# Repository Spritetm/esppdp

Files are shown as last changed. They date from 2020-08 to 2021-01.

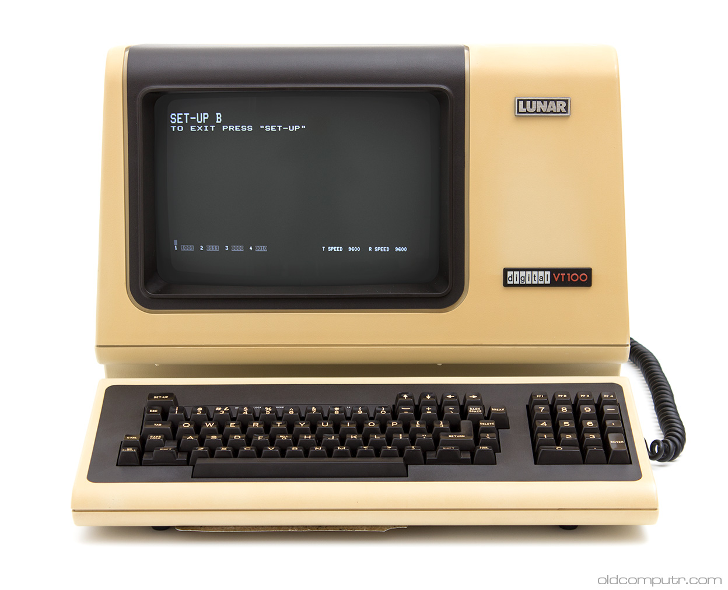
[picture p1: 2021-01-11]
case/source-images/digital_vt100-7349.jpg

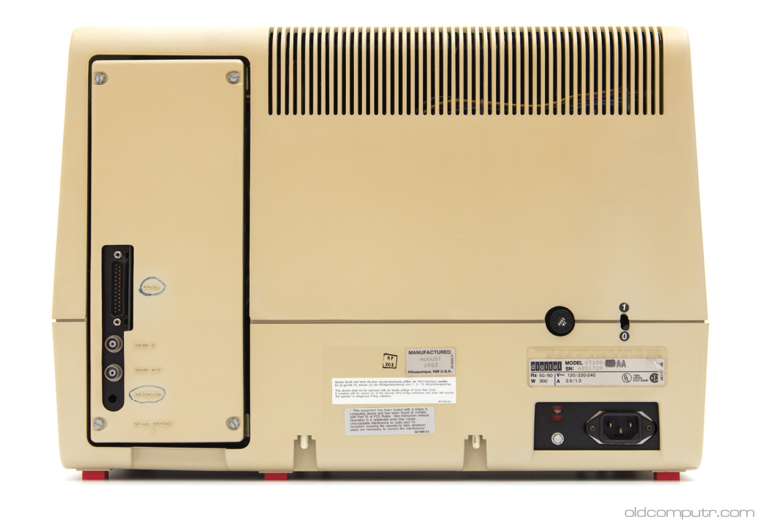
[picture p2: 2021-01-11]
case/source-images/digital_vt100-back-7363.jpg

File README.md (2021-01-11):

#What is this?

This is the source repository for esppdp, which is a tiny VT-102 scale model housing an
ESP32 emulating a PDP11. You can connect a BlueTooth keyboard to it and play the
original Tetris, or do some die-hard computing on 2.11BSD.

#Why?

Well, someone had to put back the 'mini' in 'minicomputer', right?

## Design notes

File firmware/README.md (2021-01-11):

This is the code for a PDP11 simulation on an ESP32. It also contains some code for turning
an attached LCD into a VT52/IE15 terminal as well as using a BlueTooth keyboard as an input device.

Flash it onto a board, turn it on. If you want to use a keyboard, make sure it's discoverable
over BlueTooth within the first few seconds of the ESP32 turning on. Note that the paired
BT device afterwards will be detected automatically. Unfortunately there's no easy way to clear
the pairing to use a different keyboard without erasing the flash of the ESP32 (idf.py erase-flash).

This firmware works on either the final hardware (as detailed in the ../pcb directory) as well
as a standard ESP32-Wrover-Kit development board + LCD. You can configure which board to run on
in menuconfig. (If your LCDs backlight doesn't turn on, you selected the wrong one.)

The firmware embeds a floppy disk containing RTX-11 as well as Tetris, and will start this up
automatically unless a FAT-formatted micro-SD-card with a file called 'rq.dsk' is detected. If
this file is detected, the firmware will configure a larger PDP11 and will start from the disk.
A pre-configured 2.11BSD disk has been provided in ../hard-disk-image.

To quicken uploads (if you're developing the code), you can comment out the
spiffs_create_partition_image line in CMakeLists.txt. This'll stop 'idf.py flash'
from uploading the Tetris floppy every time.

This firmware is developed on the current (11 jan 2021) master branch of ESP-IDF, but will likely
compile on ESP-IDF 4.2 and possibly other versions.

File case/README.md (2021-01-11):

This is the OpenSCAD source for the VT102 model.

Note that this requires Threadlib (for the two M3 fasteners), which is located at
https://github.com/adrianschlatter/threadlib

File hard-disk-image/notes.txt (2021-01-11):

This disk is a full-on 2.11bsd installation. Additionaly, the install is modified to add
wifid to the package. After booting this, you should be able to login as root with
the password 'esppdp11', or as the unprivileged user 'pdp11' with the same password.

To connect to a wifi network, as root, use wifid. For instance, to connect to the
access point called MyWLAN with the password MyPassword, use:
wifid -connect MyWLAN MyPassword
wifid will remember the last-connected ssid and password and reconnect to that
network on device startup.

One last note: Be sure to always shut down your 2.11BSD session. The file system is somewhat
prone to corruption if you just do the equivalent of pulling the plug instead of using
the 'halt' command to shut things down.

To use the disk, unzip and put the resulting file in the root of a FAT32-formatted 
micro-SD-card. The ESP32 SimH build will automatically pick it up and boot it. Do note
that starting up requires some manual interaction: you have to press 'enter' at the very 
first prompt ':' to boot into the OS. Then, at the prompt that follows about a minute later
'#', press ctrl-D to exit single-user mode and boot into the full system.

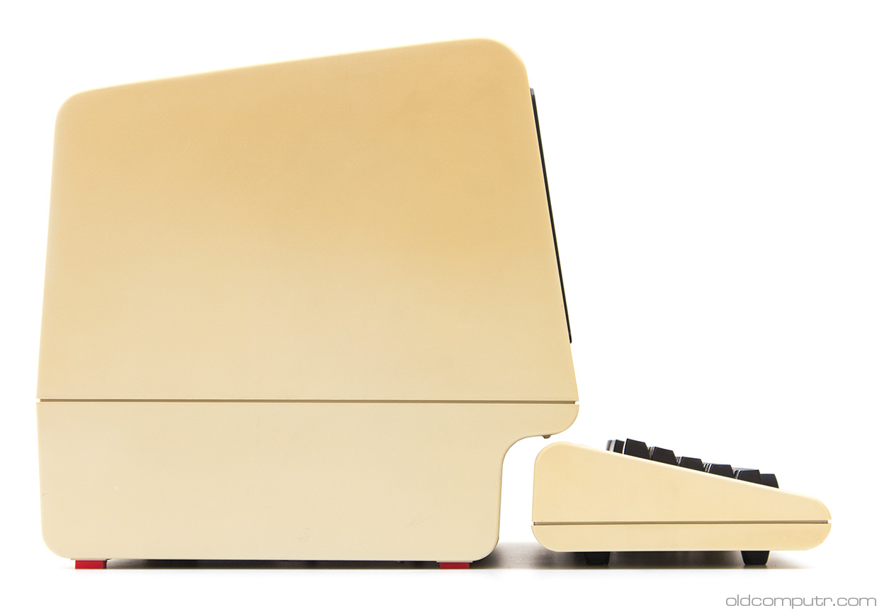
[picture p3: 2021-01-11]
case/source-images/digital_vt100-side-7362.jpg

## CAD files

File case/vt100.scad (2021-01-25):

//VT102 scale model, top+bottom half + fastener locations to hold them together, plus
//PCB and LCD mounts.
/*
 * ----------------------------------------------------------------------------
 * "THE BEER-WARE LICENSE" (Revision 42):
 * Jeroen Domburg <jeroen@spritesmods.com> wrote this file. As long as you retain 
 * this notice you can do whatever you want with this stuff. If we meet some day, 
 * and you think this stuff is worth it, you can buy me a beer in return. 
 * ----------------------------------------------------------------------------
 */

use <threadlib/threadlib.scad>

pix_scale=13; //this many pixels in one mm
$fs=0.3;

//in pixels
screen_slot_size=10;
vent_slot_size=6;
vent_slot_off=12;
slot_depth=15;
hull_thickness_mm=2.5;
hull_thickness=hull_thickness_mm*pix_scale;
lip_height=3;
show_lcd=0;

faceplate_angle=9;

/* Set this to 1 for some things that take long to render (specifically the ventilation gratings and
the DEC logo badge) */
fast_render=0;

/* What to render. Use values from 1 to 7 to select a view. For 3d printing, you want to
render 3 (bottom half) and 4 (top half). */
render_tp=3;

if (render_tp==1 || render_tp==2) {
    pcb();
    intersection() {
        union() {
            vt100_model_top();
        }
        if (render_tp==1) {
            translate([-500, 0, -500]) cube([1000,1000,1000]);
        } else {
            translate([25, -500, -500]) cube([1000,1000,1000]);
        }
    }
} else if (render_tp==3 || render_tp==4 || render_tp==5) {
    intersection() {
        union() {
            if (render_tp==3 || render_tp==5) {
                vt100_model_bottom();
            }
            if (render_tp==4 || render_tp==5) {
                rotate([0,180,0])  vt100_model_top();
            }
        }
        //translate([-500, 0, -500]) cube([1000,1000,1000]);
    }
} else if (render_tp==6) {
    pcb();
} else if (render_tp==7) {
    switch();
}


//Cutout for power switch
module switch() {
    translate([3.25, 0, 1.4]) union() {
        translate([1.5, 0, 0]) cube([2.8+3, 6.8, 1.5], center=true);
        translate([-2, 0, 0])cube([4, 3.2, 1.2], center=true);
    }
}

//PCB. Make ext 1 to also include room where plug/card goes in.
module pcb(ext) {
    exsz=ext?10:0;
    color([0.2,0.9,0]) translate([9,28,-13.5]) {
        union() {
            rotate([90,0,0]) linear_extrude(height=1.7) polygon(points=[
                [-2,13.5],[-1.3,0],[41,0],[41,49],[0,43]
            ]);
            translate([14.3,0,13.8]) cube([31.6,1,18]);
            translate([-1.5,-2.8-1.6,2.7]) rotate([0, -3, 0])translate([-exsz,0,0]) cube([exsz+6.5, 2.8, 8]);
            translate([-1.7,-2.5-1.6,19.3]) rotate([0, 4, 0])translate([-exsz,0,0]) cube([exsz+17.7, 2.5, 14]);
        }
    }
}


module lcd_placeholder_thingies() {
    scale(1/pix_scale) union() {
        translate([590 ,0, 455]) rotate([0,5,0]) cube([80,50,30]);
        translate([590 ,-250, 455]) rotate([0,5,0]) cube([80,50,30]);
        translate([700 ,-350, -20]) cube([70,500,50]);
    }
}

module pcb_placeholder_thingies() {
    union() {
        translate([7, 24, -13.5-1]) cube([10, 5.6, 3.5]);
        translate([8.5, 24, 27]) rotate([0,-9,0]) cube([10, 5.6, 4.5]);
        translate([47.3, 24, 31]) rotate([0,-9,0]) cube([6, 5.6, 4.5]);
    }
}


module vt100_model_top() {
    difference() {
        vt100_model();
        lip_diff();
    }
}


//inside this = bottom, outside = top
module lip_diff() {
    union() {
        translate([0, -500, -1000]) cube([1000,1000,1000]);
        difference() {
            scale(1/pix_scale) translate([55+hull_thickness/2,-922/2+hull_thickness/2,0])cube([736-hull_thickness,922-hull_thickness,lip_height*pix_scale]);
            scale(1/pix_scale) translate([200,-380,0])cube([400-hull_thickness,800-hull_thickness,lip_height*pix_scale]);
        }
    }
}

module vt100_model_bottom() {
    lhs=lip_height*pix_scale;
    intersection() {
        vt100_model();
        lip_diff();
    }
}

module screwpost() {
    translate([25,0,-16]) {
        cylinder(49.5, d=5.5+4);
    }
}

module screwpost_inside() {
    translate([25,0,-50-1.5]) {
        cylinder(50, d=5.5);
        cylinder(50+1.51, d=3);
        translate([0,0,51.5]) cylinder(0.2, d=5); //compensate for build plate building artifact top
        translate([0,0,35]) cylinder(0.5, d=8); //compensate for build plate building artifact bot
        translate([0,0,50+9]) rotate([180,0,0]) tap("M3", turns=15);
    }
}

module vt100_model() {
    render(8) difference() {
        union() {
            scale(1/pix_scale) vt100_hull();
            lcd_placeholder_thingies();
            pcb_placeholder_thingies();
            translate([0,18,0]) screwpost();
            translate([0,-18,0]) screwpost();
            translate([4+hull_thickness_mm,-33,hull_thickness_mm-16]) cube([6.5,12, 2]);
        }
        translate([0,18,0]) screwpost_inside();
        translate([0,-18,0]) screwpost_inside();
        translate([1.5+hull_thickness_mm, -33+6, hull_thickness_mm-15.2]) switch();
        lcd();
        pcb(1);
        translate([0, 19, -12]) cube([5.5, 12, 12]);
    }

}

module lcd() {
   if (show_lcd == 1) {
    //sizes are from KD018QVFMN010 specsheet
    tol=0.25; //tolerance on outside dimensions
    translate([721/pix_scale, -400/pix_scale,23/pix_scale]) rotate([-90-faceplate_angle,180, -90]) union() {
        translate([-tol/2,-tol/2,-tol/2]) cube([46.7+tol, 34.7+tol, 2.50+tol]); //display itself
        %translate([3.2, 4.03, 0]) cube([35.52, 26.64, 2.50+tol+0.1]); //visible area, stick out a bit
    }
   }
}



module rounded_cube(c, s) {
    hull() {
        translate([s,s,s]) sphere(r=s);
        translate([c[0]-s,s,s]) sphere(r=s);
        translate([s,c[1]-s,s]) sphere(r=s);
        translate([c[0]-s,c[1]-s,s]) sphere(r=s);
        translate([s,s,c[2]-s]) sphere(r=s);
        translate([c[0]-s,s,c[2]-s]) sphere(r=s);
        translate([s,c[1]-s,c[2]-s]) sphere(r=s);
        translate([c[0]-s,c[1]-s,c[2]-s]) sphere(r=s);
    }
}

//black rounded cosmetical cube thing on the case the screen is located in
module vt100_screencube(m) {
    translate([376+m,-408+m,43+m])rounded_cube([500-m*2,593-m*2,500-m*2],40-m);
}


module vt100_hull() {
    difference() {
        vt100_case_w_screen();
        vt100_case_solid(hull_thickness);
    }
}


module vt100_case_w_screen() {
    difference() {
        vt100_case_outer();
        union() {
            translate([784-40,0,-15]) rotate([0,-faceplate_angle,0])rotate([90,0,90]) hull() {
                translate([-358,106,0]) cylinder(50,r1=0,r2=30);
                translate([132,106,0]) cylinder(50,r1=0,r2=30);
                translate([-358,422,0]) cylinder(50,r1=0,r2=30);
                translate([132,422,0]) cylinder(50,r1=0,r2=30);
            }
        }
    }
}


module vt100_case_outer() {
    union() {
        difference() {
            if (fast_render) {
                vt100_case_solid(0);
            } else {
                minkowski(){
                    vt100_case_solid(8);
                    sphere(d=8);
                }
            }
            union() {
                difference() {
                    vt100_screencube(0);
                    vt100_screencube(screen_slot_size);
                }
                if (!fast_render) {
                    for (i=[0:vent_slot_off:480]) { //side vents
                        translate([157+i, 215, 200]) cube([vent_slot_size, 180, 500]);
                    }
                    for (i=[0:vent_slot_off:580]) { //back vents
                        translate([242-385, -405+i, 300]) cube([300, vent_slot_size, 500]);
                    }
                }
            }
        }
        vt100_case_solid(slot_depth);
        if (!fast_render) {
            translate([740+8, 242, 100]) rotate([90-faceplate_angle,0,90]) scale(0.18) linear_extrude(height=30/0.18, convexity=10) {
                import("digital_badge.svg", convexity=10);
            }
        }
    }
}

/*

  A--------G
  /        |
 |         |
 B         |
 |    EE   |
  \      E-F
  C------D 

  X ->  Y V
*/



module vt100_case_solid(inset) {
    A=[120,150];
    B=[99,722];
    C=[56,545];
    D=[650,722];
    E=[730,628];
    EE=[657,556];
    F=[755,550];
    G=[655,112];
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

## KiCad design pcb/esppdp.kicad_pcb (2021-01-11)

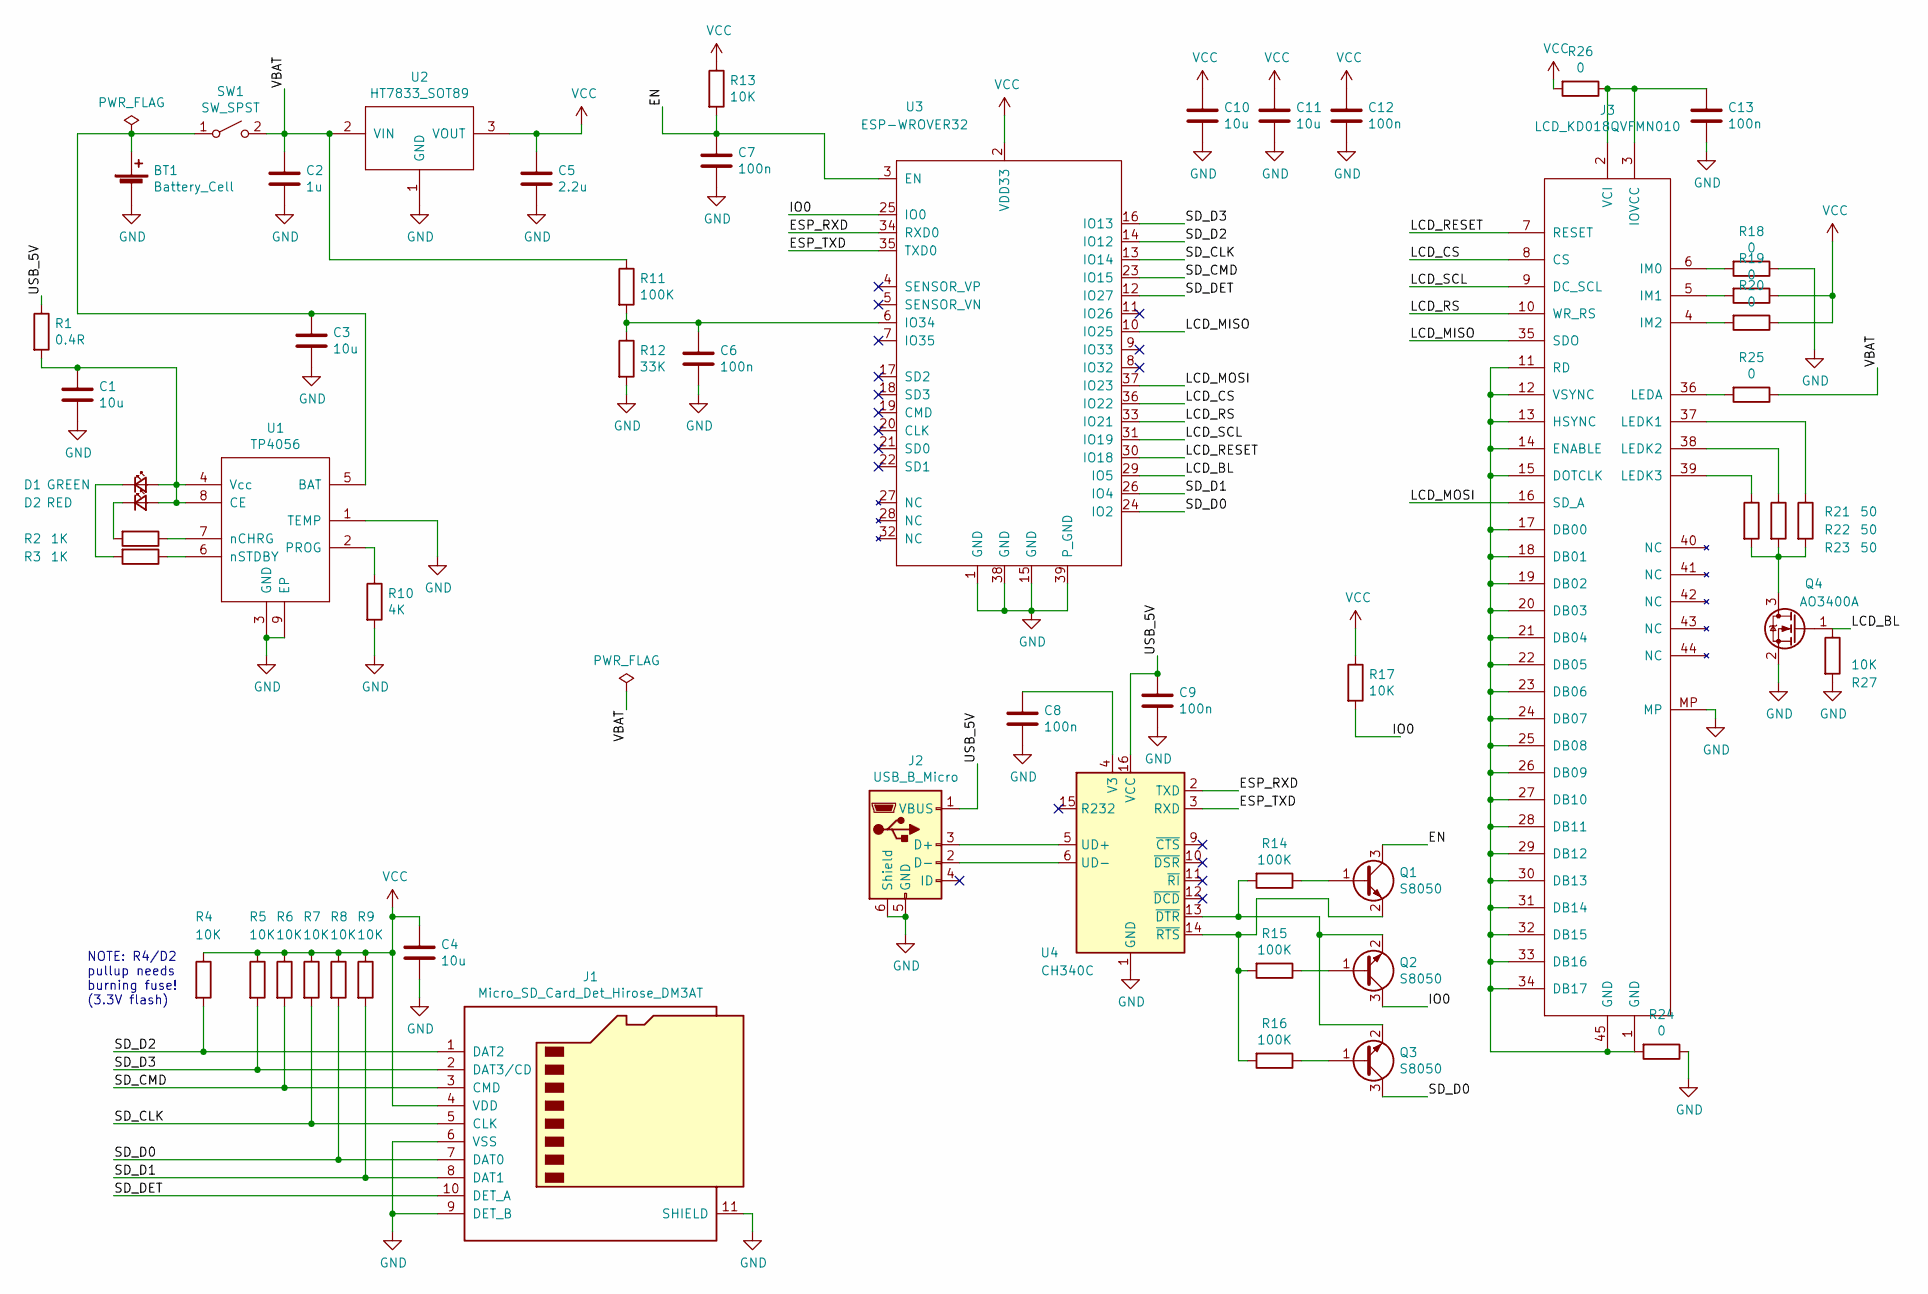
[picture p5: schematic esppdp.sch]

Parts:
BT1: Battery_Cell; PinHeader_1x02_P2.54mm_Vertical
C1, C3, C4, C10, C11: 10u; C_0805_2012Metric
C2: 1u; C_0603_1608Metric
C5: 2.2u; C_0603_1608Metric
C6, C7, C8, C9, C12, C13: 100n; C_0603_1608Metric
D1: GREEN; LED_0603_1608Metric
D2: RED; LED_0603_1608Metric
J1: Micro_SD_Card_Det_Hirose_DM3AT; microSD_HC_Hirose_DM3AT-SF-PEJM5
J2: USB_B_Micro; USB_Micro-B_China_MK5P
J3: LCD_KD018QVFMN010; Hirose_FH12-45S-0.5SH_1x45-1MP_P0.50mm_Horizontal_Descendin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
Q1, Q2, Q3: S8050; SOT-23
Q4: AO3400A; SOT-23
R1: 0.4R; R_0603_1608Metric
R2, R3: 1K; R_0603_1608Metric
R4, R5, R6, R7, R8, R9, R13, R17, R27: 10K; R_0603_1608Metric
R10: 4K; R_0603_1608Metric
R11, R14, R15, R16: 100K; R_0603_1608Metric
R12: 33K; R_0603_1608Metric
R18, R19, R20, R24, R25, R26: 0; R_0603_1608Metric
R21, R22, R23: 50; R_0603_1608Metric
SW1: SW_SPST; PinHeader_1x02_P2.54mm_Vertical
U1: TP4056; SOIC-8-1EP_3.9x4.9mm_P1.27mm_EP2.29x3mm
U2: HT7833_SOT89; SOT-89-3
U3: ESP-WROVER32; ESP-WROVER-MOD
U4: CH340C; SOIC-16_3.9x9.9mm_P1.27mm

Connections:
/EN: C7.1, Q1.3 (C), R13.2, U3.3 (EN)
/ESP_RXD: U3.34 (RXD0), U4.2 (TXD)
/ESP_TXD: U3.35 (TXD0), U4.3 (RXD)
/IO0: Q2.3 (C), R17.2, U3.25 (IO0)
/LCD_BL: Q4.1 (G), R27.1, U3.29 (IO5)
/LCD_CS: J3.8 (CS), U3.36 (IO22)
/LCD_MISO: J3.35 (SDO), U3.10 (IO25)
/LCD_MOSI: J3.16 (SD_A), U3.37 (IO23)
/LCD_RESET: J3.7 (RESET), U3.30 (IO18)
/LCD_RS: J3.10 (WR_RS), U3.33 (IO21)
/LCD_SCL: J3.9 (DC_SCL), U3.31 (IO19)
/SD_CLK: J1.5 (CLK), R7.2, U3.13 (IO14)
/SD_CMD: J1.3 (CMD), R6.2, U3.23 (IO15)
/SD_D0: J1.7 (DAT0), Q3.3 (C), R8.2, U3.24 (IO2)
/SD_D1: J1.8 (DAT1), R9.2, U3.26 (IO4)
/SD_D2: J1.1 (DAT2), R4.2, U3.14 (IO12)
/SD_D3: J1.2 (DAT3/CD), R5.2, U3.16 (IO13)
/SD_DET: J1.10 (DET_A), U3.12 (IO27)
/USB_5V: C9.1, J2.1 (VBUS), R1.1, U4.16 (VCC)
/VBAT: C2.1, R11.1, R25.1, SW1.2 (B), U2.2 (VIN)
GND: BT1.2 (-), C1.2, C2.2, C3.2, C4.2, C5.2, C6.2, C7.2, C8.2, C9.2, C10.2, C11.2, C12.2, C13.2, J1.6 (VSS), J1.9 (DET_B), J1.11 (SHIELD), J2.5 (GND), J2.6 (Shield), J3.MP, Q4.2 (S), R10.2, R12.2, R18.1, R24.1, R27.2, U1.1 (TEMP), U1.3 (GND), U1.9 (EP), U2.1 (GND), U3.1 (GND), U3.15 (GND), U3.38 (GND), U3.39 (P_GND), U4.1 (GND)
unnamed: BT1.1 (+), C3.1, SW1.1 (A), U1.5 (BAT)
unnamed: C1.1, D1.2 (A), D2.2 (A), R1.2, U1.4 (Vcc), U1.8 (CE)
unnamed: C6.1, R11.2, R12.1, U3.6 (IO34)
unnamed: C8.1, U4.4 (V3)
unnamed: C13.1, J3.2 (VCI), J3.3 (IOVCC), R26.1
unnamed: D1.1 (K), R3.2
unnamed: D2.1 (K), R2.2
unnamed: J2.2 (D-), U4.6 (UD-)
unnamed: J2.3 (D+), U4.5 (UD+)
unnamed: J3.1 (GND), J3.11 (RD), J3.12 (VSYNC), J3.13 (HSYNC), J3.14 (ENABLE), J3.15 (DOTCLK), J3.17 (DB00), J3.18 (DB01), J3.19 (DB02), J3.20 (DB03), J3.21 (DB04), J3.22 (DB05), J3.23 (DB06), J3.24 (DB07), J3.25 (DB08), J3.26 (DB09), J3.27 (DB10), J3.28 (DB11), J3.29 (DB12), J3.30 (DB13), J3.31 (DB14), J3.32 (DB15), J3.33 (DB16), J3.34 (DB17), J3.45 (GND), R24.2
unnamed: J3.4 (IM2), R20.2
unnamed: J3.5 (IM1), R19.2
unnamed: J3.6 (IM0), R18.2
unnamed: J3.36 (LEDA), R25.2
unnamed: J3.37 (LEDK1), R23.1
unnamed: J3.38 (LEDK2), R22.1
unnamed: J3.39 (LEDK3), R21.1
unnamed: Q1.1 (B), R14.1
unnamed: Q1.2 (E), R15.2, R16.2, U4.14 (~RTS)
unnamed: Q2.1 (B), R15.1
unnamed: Q2.2 (E), Q3.2 (E), R14.2, U4.13 (~DTR)
unnamed: Q3.1 (B), R16.1
unnamed: Q4.3 (D), R21.2, R22.2, R23.2
unnamed: R2.1, U1.7 (nCHRG)
unnamed: R3.1, U1.6 (nSTDBY)
unnamed: R10.1, U1.2 (PROG)
VCC: C4.1, C5.1, C10.1, C11.1, C12.1, J1.4 (VDD), R4.1, R5.1, R6.1, R7.1, R8.1, R9.1, R13.1, R17.1, R19.1, R20.1, R26.2, U2.3 (VOUT), U3.2 (VDD33)

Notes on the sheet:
NOTE: R4/D2 pullup needs burning fuse! (3.3V flash)

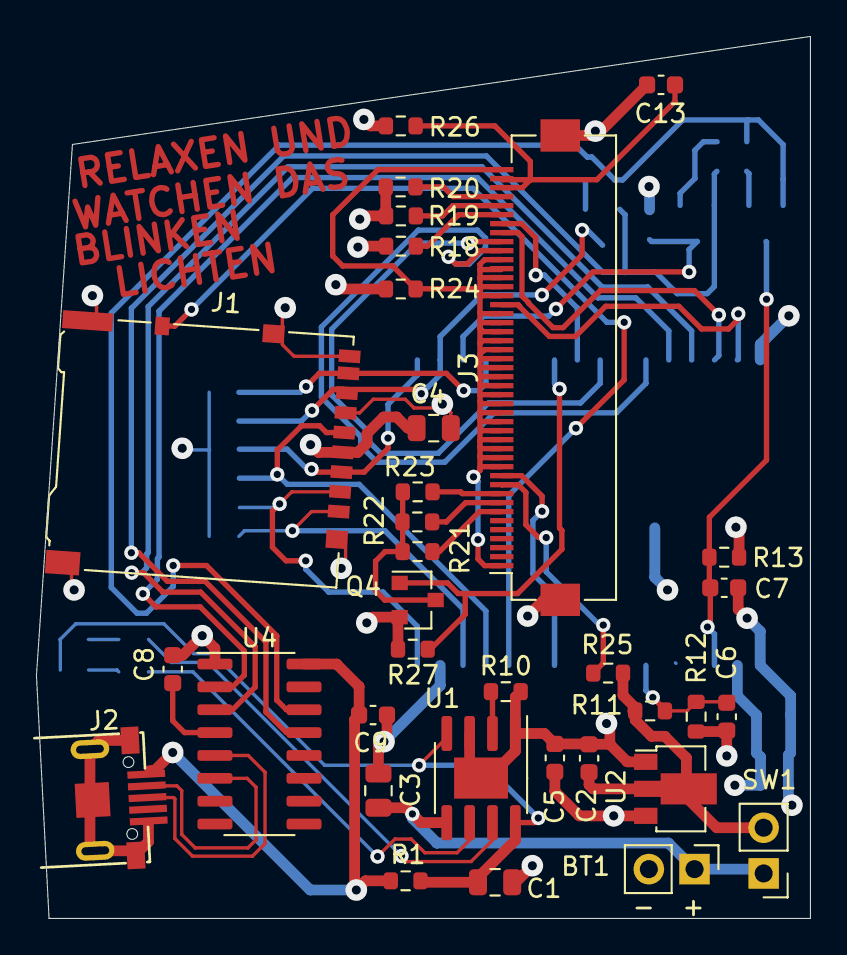
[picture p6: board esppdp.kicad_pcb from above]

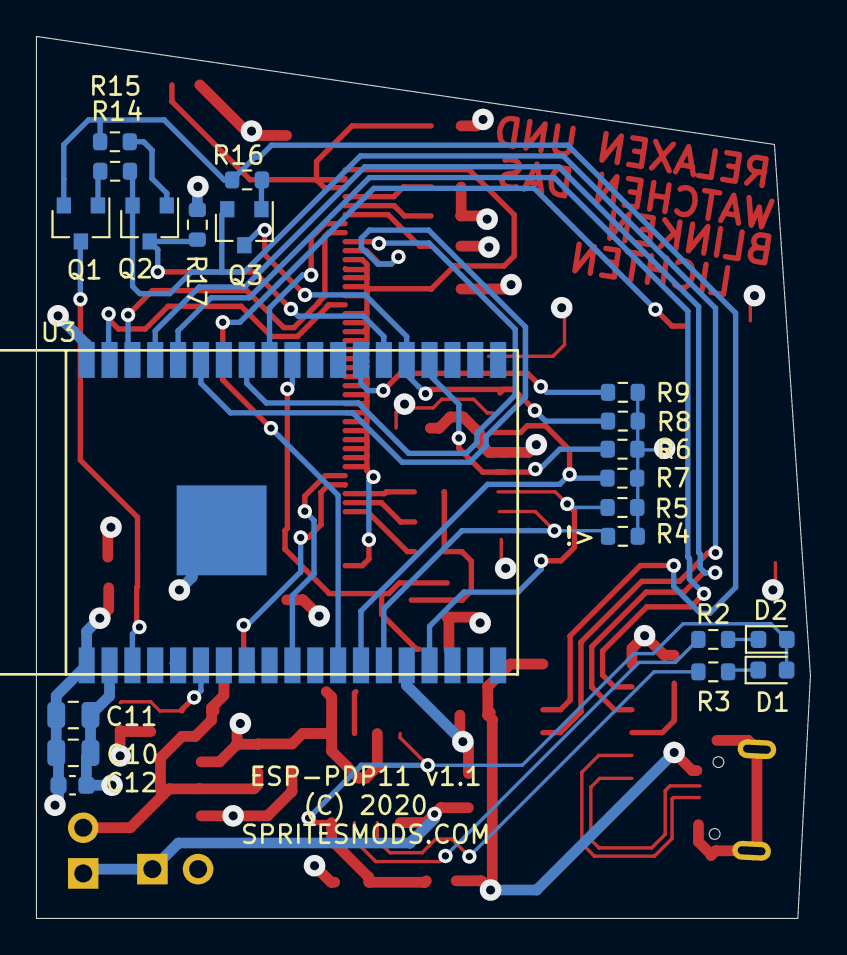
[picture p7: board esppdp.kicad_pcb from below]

Board: 4 copper layers, 43.0 x 49.0 mm, 55 parts (21 on the bottom side), 48 nets.

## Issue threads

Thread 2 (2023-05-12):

build fails with format errors

leifj, 2023-05-12:

leifj, 2023-05-12:
One example:

/home/leifj/esppdp/firmware/main/pdp11_rq.c:3286:58: warning: format '%d' expects argument of type 'int', but argument 3 has type 'uint32' {aka 'long unsigned int'} [-Wformat=]

SvenMb, 2023-08-31:
Add
`component_compile_options(-Wno-error=format= -Wno-format)`
to firmware/main/CMakeLists.txt as a workaround.

This should be fixed in next esp-idf version.

regards
Sven

Isysxp, 2023-10-09:
Dear Sprite_tm,

 You have done a stunning job here of stripping Simh down to produce a suitable image for the ESP32. I have looked into this in the past and given up in despair! So I built a much simpler PDP11 emulator. Anyway, the only problem with the repo is as above in that trying to build this with IDF 5.0 generates lots of errors (warnings). I have attached a rather dubious patch to sort this out. In addition, I have also changed some of the options in sdkconfig. I have attached this file as well as the format has changed from IDF 4->5.   The final image now runs fine on my Wrover kit.
(Google Drive)  https://drive.google.com/file/d/192e8-08gp3iPm5B2T6XzKR-vhc4VgO48/view?usp=sharing
[EspPdp11.patch](https://github.com/Spritetm/esppdp/files/12847871/EspPdp11.patch)

Spritetm, 2023-10-15:
@Isysxp Thanks for the patch! Unfortunately, it seems to be misformed, I can't get it to apply (patch says 'Only garbage was found in the patch input.' and on casual inspection at least the filenames to patch are missing)

Isysxp, 2023-10-15:
Well, this is embarrassing. I used WinMerge to create this patch and apologies as there does not seem to be any way to use patches in this format!!!! So, I have created a fork with the updated code which I hope is OK. I would note that this is not a brilliant solution and there are still many build warnings. However, it is adequate for anyone using the latest IDF install.

Spritetm, 2023-10-16:
Sure, if you can tell me where the fork is, I can pull from that, or you can see if you can create a pull request myself.

Isysxp, 2023-10-17:
I have created it in https://github.com/Isysxp/esppdp.

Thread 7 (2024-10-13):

Gerber file?

andrebruton, 2024-10-13:
Can someone supply the Gerber file that can be used to order the finished PCB from one of the online PCB manufacturers like PCBWay. They do not use KiCAD files

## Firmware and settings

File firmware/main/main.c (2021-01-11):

//Main code for pdp11 emulator thing
/*
 * ----------------------------------------------------------------------------
 * "THE BEER-WARE LICENSE" (Revision 42):
 * Jeroen Domburg <jeroen@spritesmods.com> wrote this file. As long as you retain 
 * this notice you can do whatever you want with this stuff. If we meet some day, 
 * and you think this stuff is worth it, you can buy me a beer in return. 
 * ----------------------------------------------------------------------------
 */

#include <stdio.h>
#include "sdkconfig.h"
#include "freertos/FreeRTOS.h"
#include "freertos/task.h"
#include "esp_system.h"
#include "esp_spi_flash.h"
#include "esp_err.h"
#include "esp_log.h"
#include "esp_timer.h"
#include "esp_spiffs.h"
#include "ie15lcd.h"
#include "nvs_flash.h"
#include "bthid.h"
#include "esp_vfs_fat.h"
#include "driver/sdmmc_host.h"
#include "driver/sdspi_host.h"
#include "driver/spi_common.h"
#include "sdmmc_cmd.h"
#include "sdkconfig.h"
#include "wifi_if.h"
#include "wifid.h"
#include "wifid_iface.h"
#include "esp_timer.h"

#define TAG "main"

int main(int argc, char **argv);

#if CONFIG_HEAP_TRACING_STANDALONE
#include "esp_heap_trace.h"
#define NUM_RECORDS 100
static heap_trace_record_t trace_record[NUM_RECORDS]; // This buffer must be in internal RAM
#endif

//ESP-IDF doesn't implement nanosleep, but SIMH needs it. We implement it here
//using an esp_timer. (Note this code is not re-entrant, do not try to sleep
//from multiple threads, if you need a generic nanosleep implementation look
//elsewhere!)

static esp_timer_handle_t nanosleep_timer;
static TaskHandle_t nanosleep_task = NULL;

void nanosleep_callback(void *arg) {
	xTaskNotifyGive(nanosleep_task);
}

void nanosleep_init() {
	const esp_timer_create_args_t args={
		.callback=nanosleep_callback,
		.arg=NULL,
		.dispatch_method=ESP_TIMER_TASK
	};
	esp_timer_create(&args, &nanosleep_timer);
}

//note: not reentrant!
int nanosleep(const struct timespec *req, struct timespec *rem) {
	//Note: We don't have signals; no need to write to rem
	nanosleep_task=xTaskGetCurrentTaskHandle();
	uint64_t wait_us=req->tv_nsec/1000UL+req->tv_sec*1000000UL;
	esp_timer_start_once(nanosleep_timer, wait_us);
	ulTaskNotifyTake(pdFALSE, portMAX_DELAY);
	return 0;
}



void app_main(void) {
	esp_err_t ret;
#if CONFIG_HEAP_TRACING_STANDALONE
	ESP_ERROR_CHECK( heap_trace_init_standalone(trace_record, NUM_RECORDS) );
#endif

	//Initialize NVS
	ret = nvs_flash_init();
	if (ret == ESP_ERR_NVS_NO_FREE_PAGES || ret == ESP_ERR_NVS_NEW_VERSION_FOUND) {
		ESP_ERROR_CHECK(nvs_flash_erase());
		ret = nvs_flash_init();
	}
	ESP_ERROR_CHECK(ret);

	ie15_init();
	//We cheat here: as the buffer in the IE15 emu is only 8 bytes, the following routine
	//will only finish after the initialization is complete.
	const char signon[]="Initializing emulator...\r\n";
	for (const char *p=signon; *p!=0; p++) ie15_sendchar(*p);

	//Initialize SD-card, if possible
	esp_vfs_fat_sdmmc_mount_config_t mount_config = {
		.format_if_mount_failed = false,
		.max_files = 2,
		.allocation_unit_size = 16 * 1024
	};
	sdmmc_card_t* card;

	sdmmc_host_t host = SDMMC_HOST_DEFAULT();
//	host.max_freq_khz=5000;
	sdmmc_slot_config_t slot_config = SDMMC_SLOT_CONFIG_DEFAULT();
	// GPIOs 15, 2, 4, 12, 13 should have external 10k pull-ups.
	// Internal pull-ups are not sufficient. However, enabling internal pull-ups
	// does make a difference some boards, so we do that here.
	gpio_set_pull_mode(15, GPIO_PULLUP_ONLY);	// CMD, needed in 4- and 1- line modes
	gpio_set_pull_mode(2, GPIO_PULLUP_ONLY);	// D0, needed in 4- and 1-line modes
	gpio_set_pull_mode(4, GPIO_PULLUP_ONLY);	// D1, needed in 4-line mode only
	gpio_set_pull_mode(12, GPIO_PULLUP_ONLY);	// D2, needed in 4-line mode only
	gpio_set_pull_mode(13, GPIO_PULLUP_ONLY);	// D3, needed in 4- and 1-line modes
	ret = esp_vfs_fat_sdmmc_mount("/sdcard", &host, &slot_config, &mount_config, &card);
	if (ret != ESP_OK) {
		ESP_LOGE(TAG, "SD-card: Failed to mount filesystem.");
		const char noflopstr[]="No SD card. Booting from built-in floppy.\r\n";
		for (const char *p=noflopstr; *p!=0; p++) ie15_sendchar(*p);
	} else {
		sdmmc_card_print_info(stdout, card);
	}

	//Mount spiffs. This contains a floppy image.
	esp_vfs_spiffs_conf_t conf = {
		.base_path = "/spiffs",
		.partition_label = NULL,
		.max_files = 2,
		.format_if_mount_failed = true
	};
	// Use settings defined above to initialize and mount SPIFFS filesystem.
	// Note: esp_vfs_spiffs_register is an all-in-one convenience function.
	ret = esp_vfs_spiffs_register(&conf);

	if (ret != ESP_OK) {
		if (ret == ESP_FAIL) {
			ESP_LOGE(TAG, "Failed to mount or format filesystem");
		} else if (ret == ESP_ERR_NOT_FOUND) {
			ESP_LOGE(TAG, "Failed to find SPIFFS partition");
		} else {
			ESP_LOGE(TAG, "Failed to initialize SPIFFS (%s)", esp_err_to_name(ret));
		}
		return;
	}

	bthid_start();

	nanosleep_init();

#if CONFIG_HEAP_TRACING_STANDALONE
	ESP_ERROR_CHECK( heap_trace_init_standalone(trace_record, NUM_RECORDS) );
	ESP_ERROR_CHECK( heap_trace_start(HEAP_TRACE_LEAKS) );
#endif
	
	//Start up main SIMH emulator
	char *args[]={"simh", 0};
	main(1, args);		//Note: This is in scp.c and is the SIMH main routine.
	fflush(stdout);
	esp_restart();
}

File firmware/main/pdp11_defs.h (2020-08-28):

/* pdp11_defs.h: PDP-11 simulator definitions

   Copyright (c) 1993-2017, Robert M Supnik

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
   Except as contained in this notice, the name of Robert M Supnik shall not be
   used in advertising or otherwise to promote the sale, use or other dealings
   in this Software without prior written authorization from Robert M Supnik.

   The author gratefully acknowledges the help of Max Burnet, Megan Gentry,
   and John Wilson in resolving questions about the PDP-11

   10-Feb-17    RMS     Fixed RJS11 register block length (Mark Hill)
   19-Jan-17    RMS     Moved CR11 to BR6, leaving CD11 at BR4 (Mark Pizzolato)
   10-Mar-16    RMS     Added UC15 support
   30-Dec-15    RMS     Added NOBVT option
   23-Oct-13    RMS     Added cpu_set_boot prototype
   02-Sep-13    RMS     Added third Massbus adapter and RS drive
   11-Dec-11    RMS     Fixed priority of PIRQ vs IO; added INT_INTERNALn
   22-May-10    RMS     Added check for 64b definitions
   19-Nov-08    RMS     Moved I/O support routines to I/O library
   16-May-08    RMS     Added KE11A, DC11 support
   02-Feb-08    RMS     Fixed DMA memory address limit test (found by John Dundas)
   25-Jan-08    RMS     Added RC11, KG11A support (from John Dundas)
   16-Dec-06    RMS     Added TA11 support
   29-Oct-06    RMS     Added clock coscheduling
   06-Jul-06    RMS     Added multiple KL11/DL11 support
   26-Jun-06    RMS     Added RF11 support
   24-May-06    RMS     Added 11/44 DR support (from CIS diagnostic)
   17-May-06    RMS     Added CR11/CD11 support (from John Dundas)
   30-Sep-04    RMS     Added Massbus support
                        Removed Map_Addr prototype
                        Removed map argument from Unibus routines
                        Added framework for model selection
   28-May-04    RMS     Added DHQ support
   25-Jan-04    RMS     Removed local debug logging support
   22-Dec-03    RMS     Added second DEUNA/DELUA support
   18-Oct-03    RMS     Added DECtape off reel message
   19-May-03    RMS     Revised for new conditional compilation
   05-Apr-03    RMS     Fixed bug in MMR1 update (found by Tim Stark)
   28-Feb-03    RMS     Added TM logging support
   19-Jan-03    RMS     Changed mode definitions for Apple Dev Kit conflict
   11-Nov-02    RMS     Changed log definitions to be VAX compatible
   10-Oct-02    RMS     Added vector information to DIB
                        Changed DZ11 vector to Unibus standard
                        Added DEQNA/DELQA, DEUNA/DELUA support
                        Added multiple RQDX3, autoconfigure support
   12-Sep-02    RMS     Added TMSCP, KW11P,and RX211 support
   28-Apr-02    RMS     Clarified PDF ACF mnemonics
   22-Apr-02    RMS     Added HTRAP, BPOK maint register flags, MT_MAXFR
   06-Mar-02    RMS     Changed system type to KDJ11A
   20-Jan-02    RMS     Added multiboard DZ11 support
   09-Nov-01    RMS     Added bus map support
   07-Nov-01    RMS     Added RQDX3 support
   26-Oct-01    RMS     Added symbolic definitions for IO page
   19-Oct-01    RMS     Added DZ definitions
   15-Oct-01    RMS     Added logging capabilities
   07-Sep-01    RMS     Revised for multilevel interrupts
   01-Jun-01    RMS     Added DZ11 support
   23-Apr-01    RMS     Added RK611 support
   05-Apr-01    RMS     Added TS11/TSV05 support
   10-Feb-01    RMS     Added DECtape support
*/

#ifndef PDP11_DEFS_H
#define PDP11_DEFS_H   0

#ifndef VM_PDP11
#define VM_PDP11        0
#endif

#include "sim_defs.h"                                   /* simulator defns */
#include <setjmp.h>

#if defined(USE_INT64) || defined(USE_ADDR64)
#error "PDP-11 does not support 64b values!"
#endif

/* Architectural constants */

#define STKL_R          0340                            /* stack limit */
#define STKL_Y          0400
#define VASIZE          0200000                         /* 2**16 */
#define VAMASK          (VASIZE - 1)                    /* 2**16 - 1 */
#define MEMSIZE64K      0200000                         /* 2**16 */
#define UNIMEMSIZE      001000000                       /* 2**18 */
#define UNIMASK         (UNIMEMSIZE - 1)                /* 2**18 - 1 */
#define IOPAGEBASE      017760000                       /* 2**22 - 2**13 */
#define IOPAGESIZE      000020000                       /* 2**13 */
#define IOPAGEMASK      (IOPAGESIZE - 1)                /* 2**13 - 1 */
#define MAXMEMSIZE      020000000                       /* 2**22 */
#define PAMASK          (MAXMEMSIZE - 1)                /* 2**22 - 1 */
#define MEMSIZE         (cpu_unit.capac)
#define DMASK           0177777
#define BMASK           0377

/* CPU models */
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

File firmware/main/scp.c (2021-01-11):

/*
 This is a thoroughly hacked-up version of the SIMH scp.c file, keeping only what's needed to
 start up emulation. All hackwork is (c) 202 Sprite_tm.

 Original copyright follows:
*/
/* scp.c: simulator control program

   Copyright (c) 1993-2016, Robert M Supnik

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
   Except as contained in this notice, the name of Robert M Supnik shall not be
   used in advertising or otherwise to promote the sale, use or other dealings
   in this Software without prior written authorization from Robert M Supnik.
*/


#include "sim_defs.h"
#include "sim_rev.h"
#include "sim_disk.h"
#include "sim_ether.h"
#include "sim_card.h"
#include "sim_term.h"
#include "sim_serial.h"
#include "sim_sock.h"
#include "sim_frontpanel.h"
#include <signal.h>
#include <ctype.h>
#include <time.h>
#include <math.h>
#include <unistd.h>
#include <sys/stat.h>
#include <setjmp.h>
#include <sys/stat.h>
#include "wifi_if.h"

FILE *sim_deb = NULL;                                   /* debug file */

t_value (*sim_vm_pc_value) (void) = NULL;
t_bool (*sim_vm_is_subroutine_call) (t_addr **ret_addrs) = NULL;
uint32 sim_brk_dflt = 0;
uint32 sim_brk_types = 0;
BRKTYPTAB *sim_brk_type_desc = NULL;
const char **sim_clock_precalibrate_commands = NULL;
t_value *sim_eval = NULL;
extern uint32_t sim_emax;
int32 sim_switches=0;
int32_t sim_switch_number=0;
int sim_internal_device_count=0;
DEVICE **sim_internal_devices;

const t_value width_mask[] = { 0,
    0x1, 0x3, 0x7, 0xF,
    0x1F, 0x3F, 0x7F, 0xFF,
    0x1FF, 0x3FF, 0x7FF, 0xFFF,
    0x1FFF, 0x3FFF, 0x7FFF, 0xFFFF,
    0x1FFFF, 0x3FFFF, 0x7FFFF, 0xFFFFF,
    0x1FFFFF, 0x3FFFFF, 0x7FFFFF, 0xFFFFFF,
    0x1FFFFFF, 0x3FFFFFF, 0x7FFFFFF, 0xFFFFFFF,
    0x1FFFFFFF, 0x3FFFFFFF, 0x7FFFFFFF, 0xFFFFFFFF
    };



t_stat sprint_val (char *buffer, t_value val, uint32 radix,
    uint32 width, uint32 format)
{
#define MAX_WIDTH ((int) ((CHAR_BIT * sizeof (t_value) * 4 + 3)/3))
t_value owtest, wtest;
t_bool negative = FALSE;
int32 d, digit, ndigits, commas = 0;
char dbuf[MAX_WIDTH + 1];

if (((format == PV_LEFTSIGN) || (format == PV_RCOMMASIGN)) &&
    (0 > (t_svalue)val)) {
    val = (t_value)(-((t_svalue)val));
    negative = TRUE;
    }
for (d = 0; d < MAX_WIDTH; d++)
    dbuf[d] = (format == PV_RZRO)? '0': ' ';
dbuf[MAX_WIDTH] = 0;
d = MAX_WIDTH;
do {
    d = d - 1;
    digit = (int32) (val % radix);
    val = val / radix;
    dbuf[d] = (char)((digit <= 9)? '0' + digit: 'A' + (digit - 10));
    } while ((d > 0) && (val != 0));
if (negative && (format == PV_LEFTSIGN))
    dbuf[--d] = '-';

switch (format) {
    case PV_LEFT:
    case PV_LEFTSIGN:
        break;
    case PV_RCOMMA:
    case PV_RCOMMASIGN:
        for (digit = 0; digit < MAX_WIDTH; digit++)
            if (dbuf[digit] != ' ')
                break;
        ndigits = MAX_WIDTH - digit;
        commas = (ndigits - 1)/3;
        for (digit=0; digit<ndigits-3; digit++)
            dbuf[MAX_WIDTH + (digit - ndigits) - (ndigits - digit - 1)/3] = dbuf[MAX_WIDTH + (digit - ndigits)];
        for (digit=1; digit<=commas; digit++)
            dbuf[MAX_WIDTH - (digit * 4)] = ',';
        d = d - commas;
        if (negative && (format == PV_RCOMMASIGN))
            dbuf[--d] = '-';
        if (width > MAX_WIDTH) {
            if (!buffer)
                return width;
            sprintf (buffer, "%*s", -((int)width), dbuf);
            return SCPE_OK;
            }
        else
            if (width > 0)
                d = MAX_WIDTH - width;
        break;
    case PV_RZRO:
    case PV_RSPC:
        wtest = owtest = radix;
        ndigits = 1;
        while ((wtest < width_mask[width]) && (wtest >= owtest)) {
            owtest = wtest;
            wtest = wtest * radix;
            ndigits = ndigits + 1;
            }
        if ((MAX_WIDTH - (ndigits + commas)) < d)
            d = MAX_WIDTH - (ndigits + commas);
        break;
    }
if (!buffer)
    return strlen(dbuf+d);
*buffer = '\0';
if (width < strlen(dbuf+d))
    return SCPE_IOERR;
strcpy(buffer, dbuf+d);
return SCPE_OK;
}


t_stat fprint_val (FILE *stream, t_value val, uint32 radix, uint32 width, uint32 format) {
	char dbuf[MAX_WIDTH + 1];
	
	if (!stream) return sprint_val (NULL, val, radix, width, format);
	if (width > MAX_WIDTH) width = MAX_WIDTH;
	sprint_val (dbuf, val, radix, width, format);
	if (fprintf (stream, "%s", dbuf) < 0) return SCPE_IOERR;
	return SCPE_OK;
}



static void _sim_vdebug (uint32 dbits, DEVICE* dptr, UNIT *uptr, const char* fmt, va_list arglist) {
	if (sim_deb && dptr && ((dptr->dctrl | (uptr ? uptr->dctrl : 0)) & dbits)) {
		vfprintf(sim_deb, fmt, arglist);
	}
}

void _sim_debug_unit (uint32 dbits, UNIT *uptr, const char* fmt, ...) {
	DEVICE *dptr = (uptr ? uptr->dptr : NULL);
	
	if (sim_deb && (((dptr ? dptr->dctrl : 0) | (uptr ? uptr->dctrl : 0)) & dbits)) {
		va_list arglist;
		va_start (arglist, fmt);
		_sim_vdebug (dbits, dptr, uptr, fmt, arglist);
		va_end (arglist);
	}
}


void _sim_debug_device (uint32 dbits, DEVICE* dptr, const char* fmt, ...) {
	if (sim_deb && dptr && (dptr->dctrl & dbits)) {
		va_list arglist;
		va_start (arglist, fmt);
		_sim_vdebug (dbits, dptr, NULL, fmt, arglist);
		va_end (arglist);
	}
}

t_stat sim_messagef (t_stat stat, const char* fmt, ...) {
	va_list arglist;
	va_start (arglist, fmt);
	vfprintf(sim_deb, fmt, arglist);
	va_end (arglist);
	return SCPE_OK;
}

void fprint_fields (FILE *stream, t_value before, t_value after, BITFIELD* bitdefs) {
	const char *debug_bstates = "01_^";
	int32 i, fields, offset;
	uint32 value, beforevalue, mask;

	for (fields=offset=0; bitdefs[fields].name; ++fields) {
		if (bitdefs[fields].offset == 0xffffffff) {		/* fixup uninitialized offsets */
			bitdefs[fields].offset = offset;
		}
		offset += bitdefs[fields].width;
	}
	for (i = fields-1; i >= 0; i--) {					/* print xlation, transition */
		if (bitdefs[i].name[0] == '\0')
			continue;
		if ((bitdefs[i].width == 1) && (bitdefs[i].valuenames == NULL)) {
			int off = ((after >> bitdefs[i].offset) & 1) + (((before ^ after) >> bitdefs[i].offset) & 1) * 2;
			fprintf(stream, "%s%c ", bitdefs[i].name, debug_bstates[off]);
		} else {
			const char *delta = "";
	
			mask = 0xFFFFFFFF >> (32-bitdefs[i].width);
			value = (uint32)((after >> bitdefs[i].offset) & mask);
			beforevalue = (uint32)((before >> bitdefs[i].offset) & mask);
			if (value < beforevalue)
				delta = "_";
			if (value > beforevalue)
				delta = "^";
			if (bitdefs[i].valuenames)
				fprintf(stream, "%s=%s%s ", bitdefs[i].name, delta, bitdefs[i].valuenames[value]);
			else
				if (bitdefs[i].format) {
					fprintf(stream, "%s=%s", bitdefs[i].name, delta);
					fprintf(stream, bitdefs[i].format, value);
					fprintf(stream, " ");
				} else {
					fprintf(stream, "%s=%s0x%X ", bitdefs[i].name, delta, value);
				}
		}
	}
}
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

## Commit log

2020-08-30 Lots of hacking but it works. Now to move it to the ESP32...
2020-09-04 Compiles for esp32; yay!
2020-09-29 Tetris works, BTHID does its thing, now to fix BSD2.11...
    [partitions.csv]
2020-10-18 Add WiFi
    [partitions.csv]
2020-10-22 Shared LWIP/PDP11 IP stack thing works, fix BT to work with WiFi as well
    [scp.c, sim_defs.h]
2020-12-17 Clean up some printfs, try to set freertos ticks lower
2021-01-11 Add pcb, wifid etc to same git repo, clean up
    [esppdp.kicad_pcb, esppdp.sch, partitions.csv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]
2021-01-11 Add copyright stuff
    [vt100.scad]
2021-01-15 pcb label move to make moar readable
    [esppdp.sch]
2021-01-20 Correct typo in model file
    Correct doubled paren in openscad
    [vt100.scad]
2021-01-20 update to remove lcd place holder
    [vt100.scad]

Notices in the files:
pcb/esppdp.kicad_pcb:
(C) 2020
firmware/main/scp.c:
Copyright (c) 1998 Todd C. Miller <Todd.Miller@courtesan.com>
